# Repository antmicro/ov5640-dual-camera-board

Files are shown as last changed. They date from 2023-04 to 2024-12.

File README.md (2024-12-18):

# Antmicro's OV5640 Dual Camera Board

Copyright (c) 2017-2024 [Antmicro](https://www.antmicro.com)

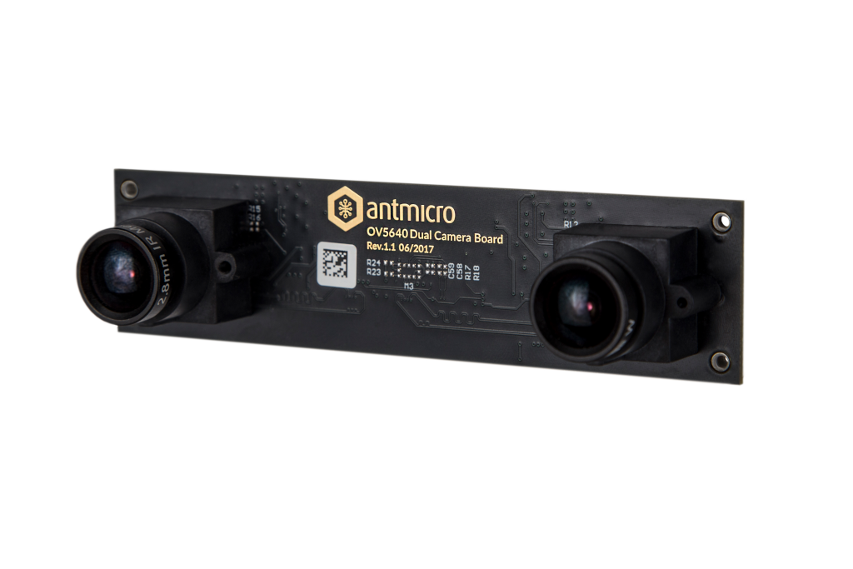
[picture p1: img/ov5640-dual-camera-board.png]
OV5640 Dual Camera Board


## Overview

This project contains open hardware design files for a camera board supporting two [OV5640](https://cdn.sparkfun.com/datasheets/Sensors/LightImaging/OV5640_datasheet.pdf) image sensors from OmniVision. 
These RGB sensors provide a rolling shutter and offer a resolution of 5MP (2591x1944).
The design files for this project are provided and maintained in KiCad.

### Project structure

The main directory contains the KiCad design files, LICENSE and README.
The remaining files are stored in the following directories:

* ``img`` - contains graphics for this README
* ``doc`` - contains generated schematics and other documentation
* ``lib`` - contains KiCad component library

## Key features

* Two OV5640 image sensors placed on a PCB
* Fastening holes spaced by 20mm for a standard S-mount lens holder
* Each sensor is accessible through an independent 2-lane MIPI CSI-2 interface
* Separate I2C buses for sensor configuration 
* Unified, 50-pin FFC interface
* On-board clock generator for driving the image sensors 

The OV5640 Dual Camera board is electrically compatible with a variety of processing platforms created by Antmicro.
Below is a list of a few selected ones:

* [Jetson Nano Baseboard](https://github.com/antmicro/jetson-nano-baseboard) supporting NVIDIA [Jetson Nano](https://developer.nvidia.com/embedded/jetson-nano), Jetson [TX2 NX](https://developer.nvidia.com/embedded/jetson-tx2-nx), Jetson [Xavier NX](https://www.nvidia.com/en-us/autonomous-machines/embedded-systems/jetson-xavier-nx/) System on Modules
* [Jetson Orin Baseboard](https://github.com/antmicro/jetson-orin-baseboard) supporting NVIDIA Jetson Orin NX, Jetson Orin Nano
* [Kria K26 Devboard](https://github.com/antmicro/kria-k26-devboard) supporting AMD-Xilinx [KRIA K26](https://www.xilinx.com/products/som/kria/k26c-commercial.html) System on Module
* [Google Coral Baseboard](https://github.com/antmicro/google-coral-baseboard) supporting [Google Coral](https://coral.ai/products/som) System on Module
* [Snapdragon 845 Baseboard](https://github.com/antmicro/snapdragon-845-baseboard) based on Quectel SA800 SoM with Qualcomm [Snapdragon 845 Mobile Platform](https://www.qualcomm.com/products/mobile/snapdragon/smartphones/snapdragon-8-series-mobile-platforms/snapdragon-845-mobile-platform)
* [Snapdragon 625 Baseboard](https://github.com/antmicro/snapdragon-625-baseboard) based on Quectel SC606T SoM with Qualcomm [Snapdragon 625 Mobile Platform](https://www.qualcomm.com/products/mobile/snapdragon/smartphones/snapdragon-6-series-mobile-platforms/snapdragon-625-mobile-platform)

## License

This project is licensed under the [Apache-2.0](LICENSE) license.

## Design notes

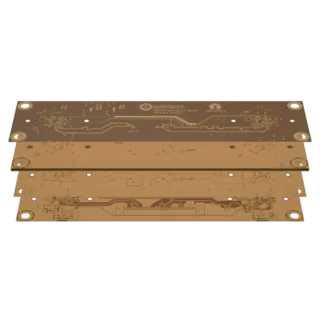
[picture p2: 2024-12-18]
assets/previews/layer1_thumbnail.webp

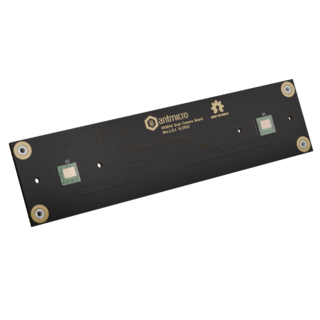
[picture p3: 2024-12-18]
assets/previews/leftT_thumbnail.png

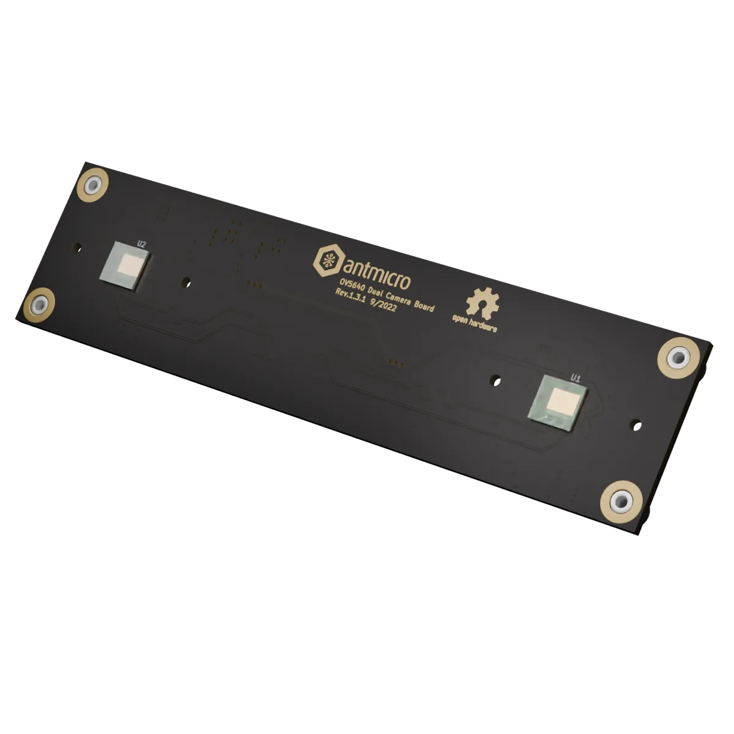
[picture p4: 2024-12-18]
assets/previews/rightT.webp

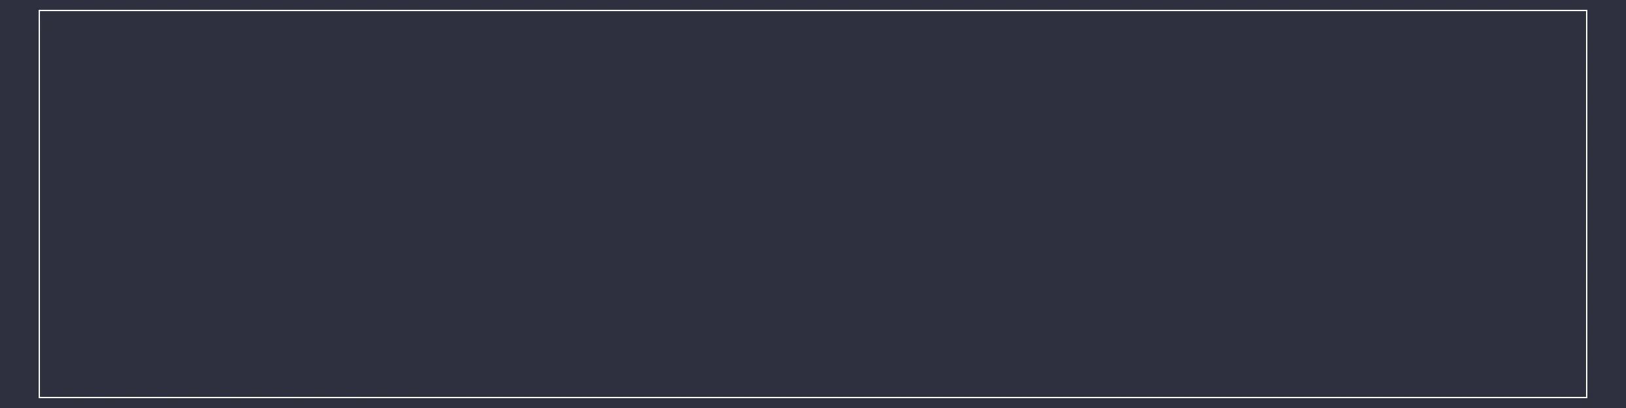
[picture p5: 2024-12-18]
assets/wireframe/wireframe_descriptions_top.webp

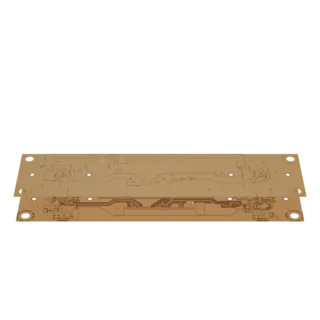
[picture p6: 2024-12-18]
assets/previews/layer3_thumbnail.webp

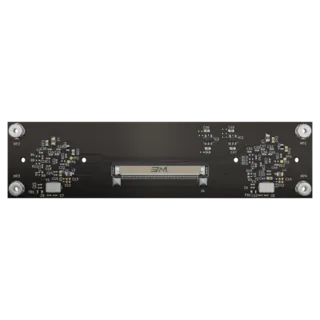
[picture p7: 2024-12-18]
assets/previews/orthoB_thumbnail.webp

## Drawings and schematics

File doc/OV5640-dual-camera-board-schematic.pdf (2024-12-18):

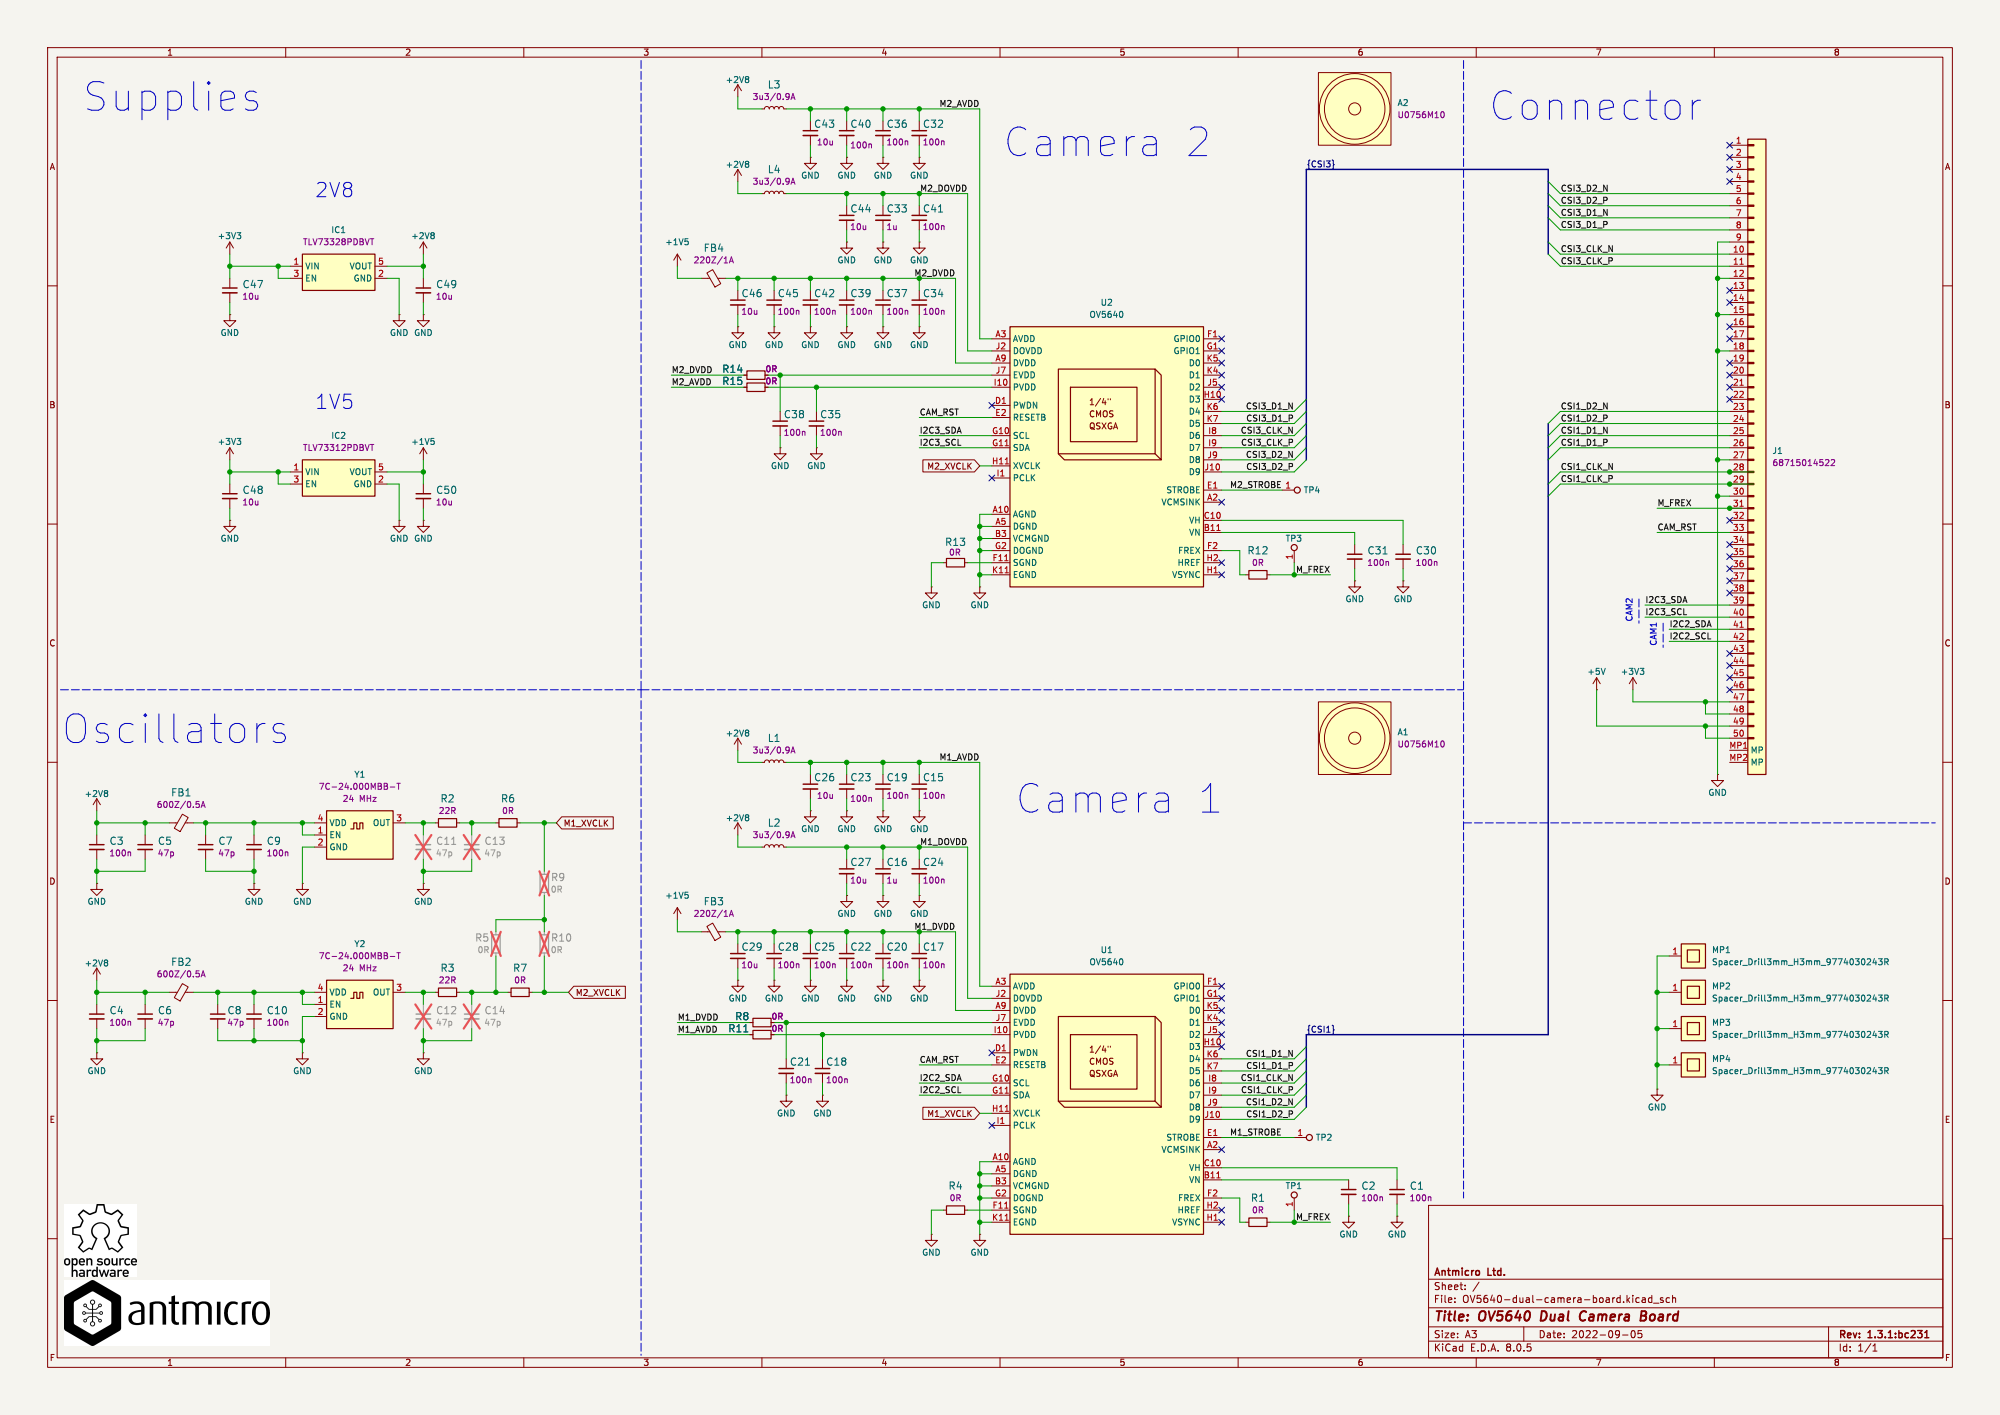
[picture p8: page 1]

Id: 1/1 Title: OV5640 Dual Camera Board

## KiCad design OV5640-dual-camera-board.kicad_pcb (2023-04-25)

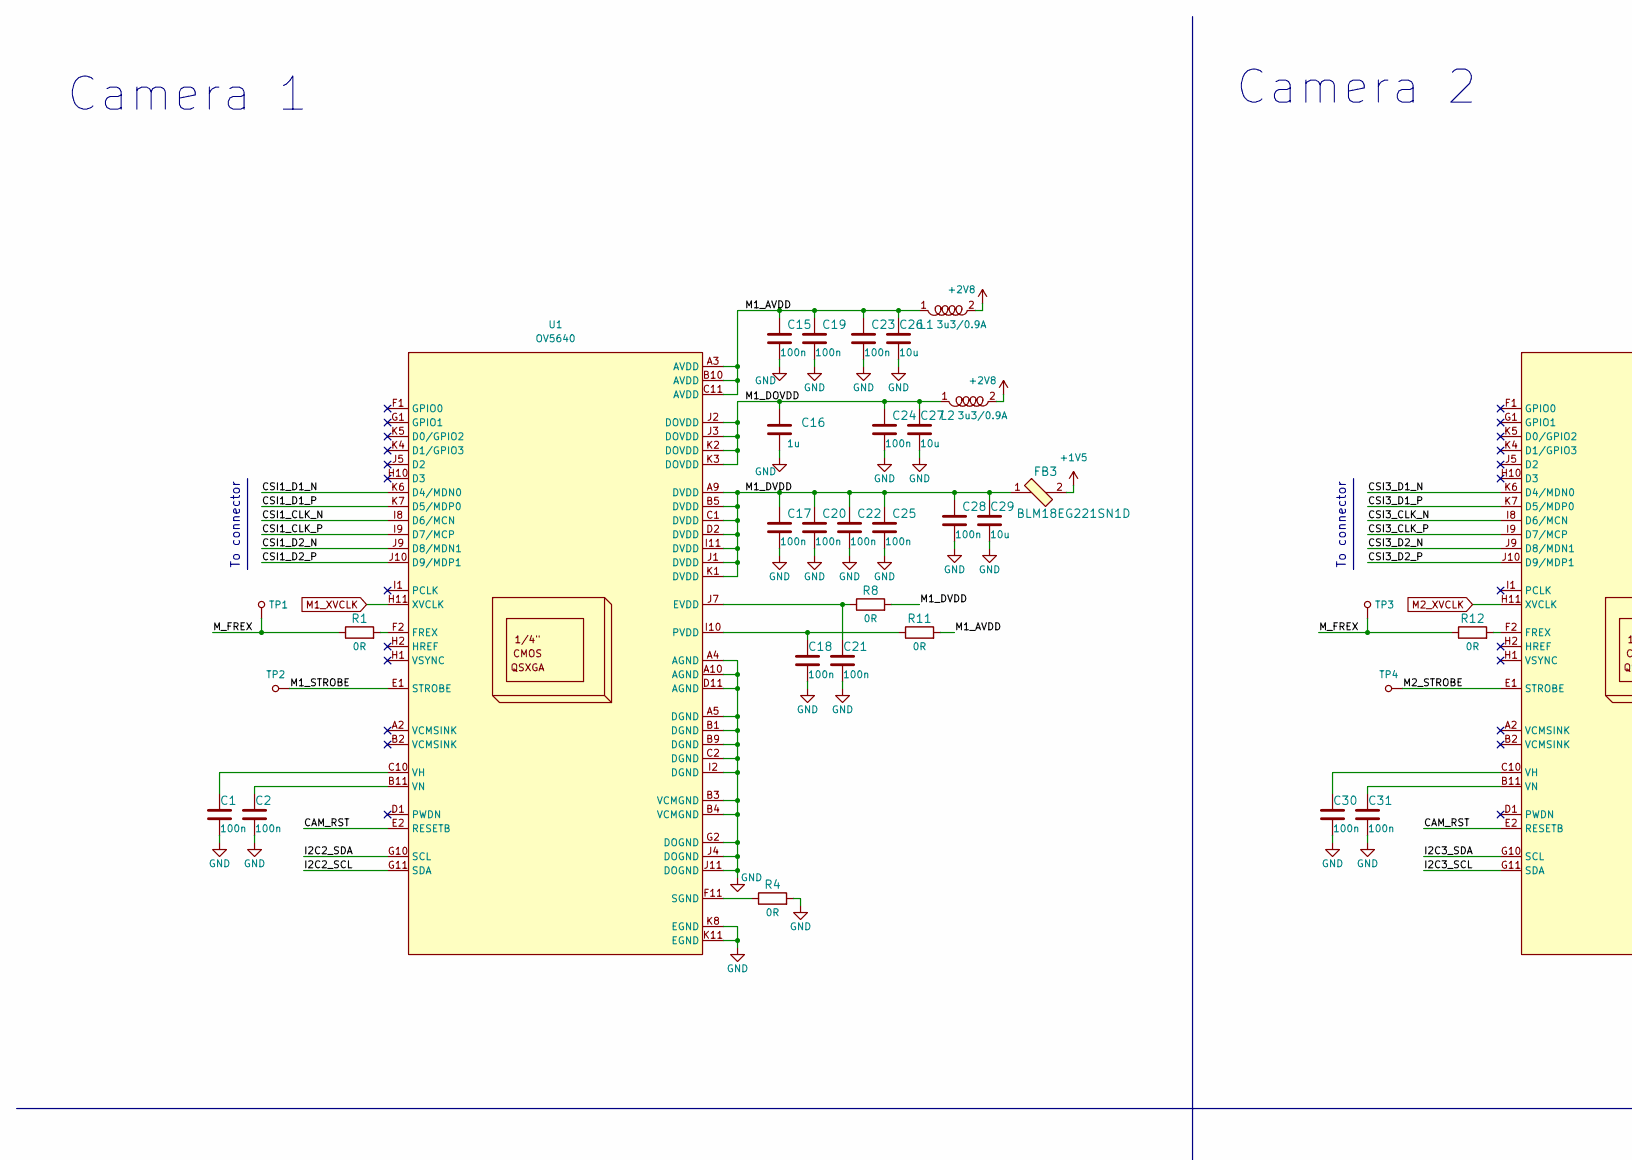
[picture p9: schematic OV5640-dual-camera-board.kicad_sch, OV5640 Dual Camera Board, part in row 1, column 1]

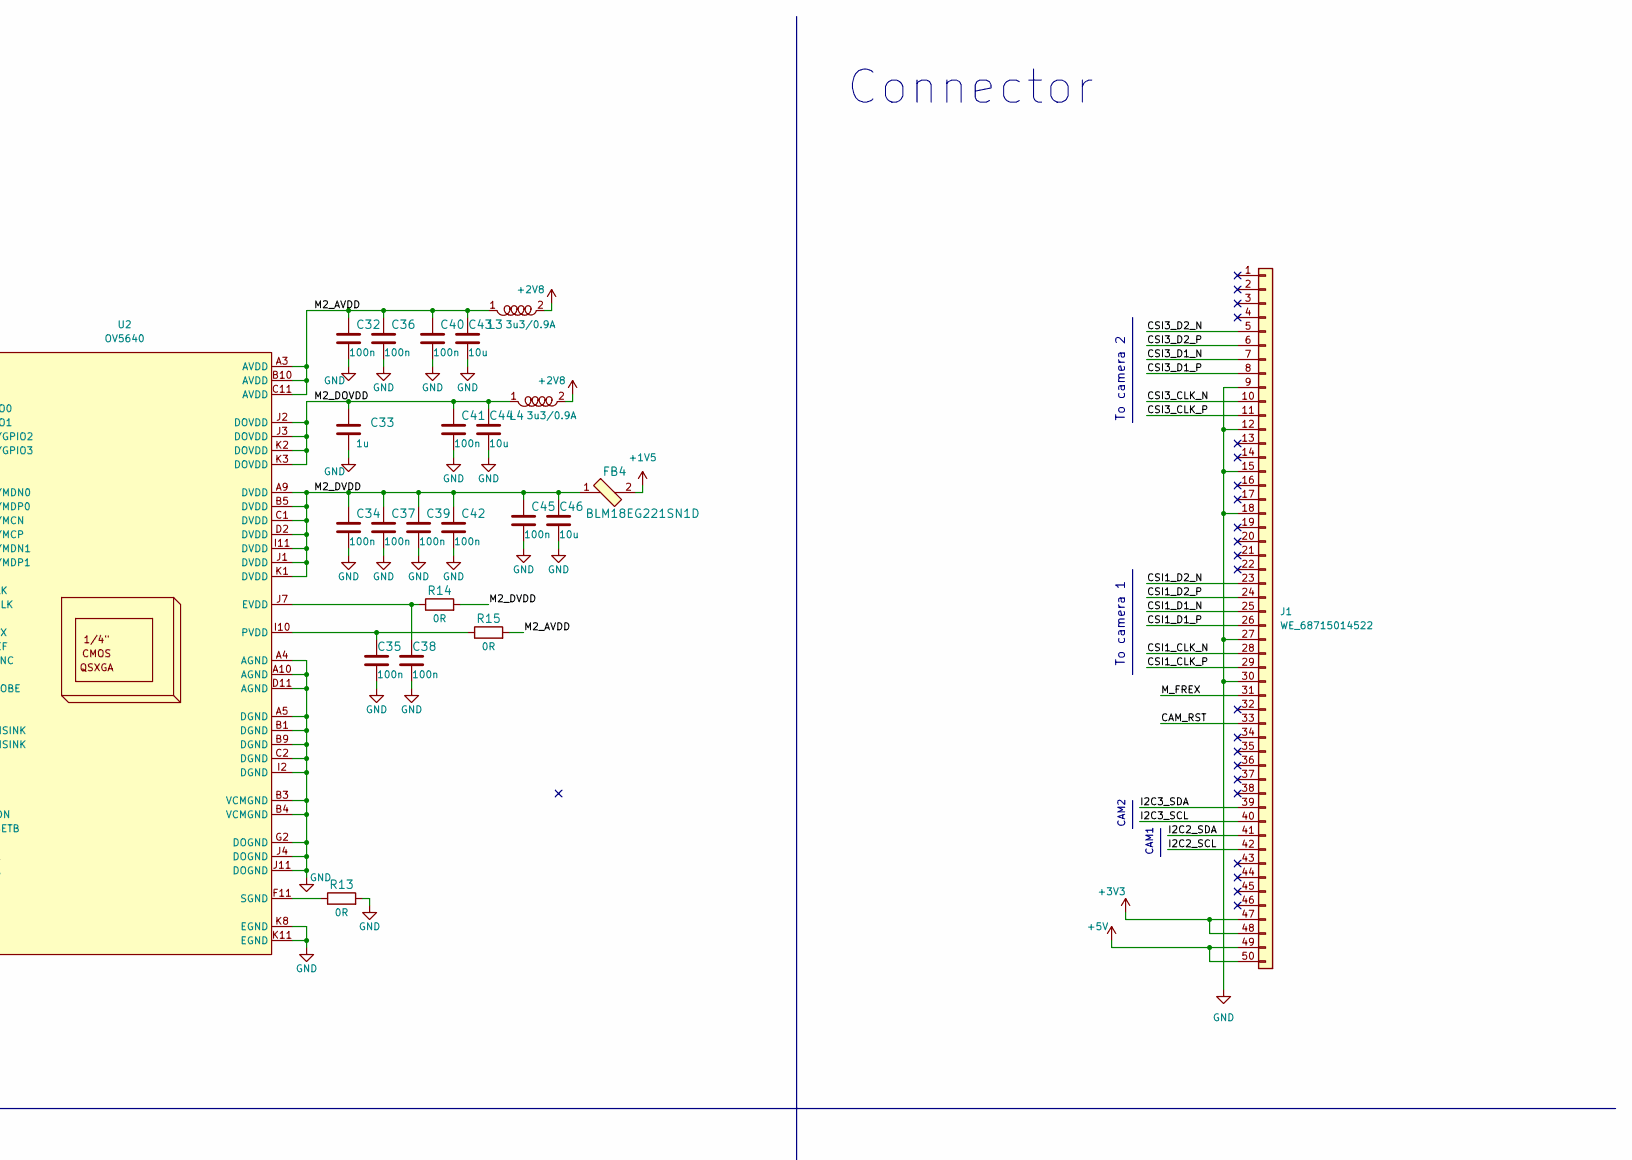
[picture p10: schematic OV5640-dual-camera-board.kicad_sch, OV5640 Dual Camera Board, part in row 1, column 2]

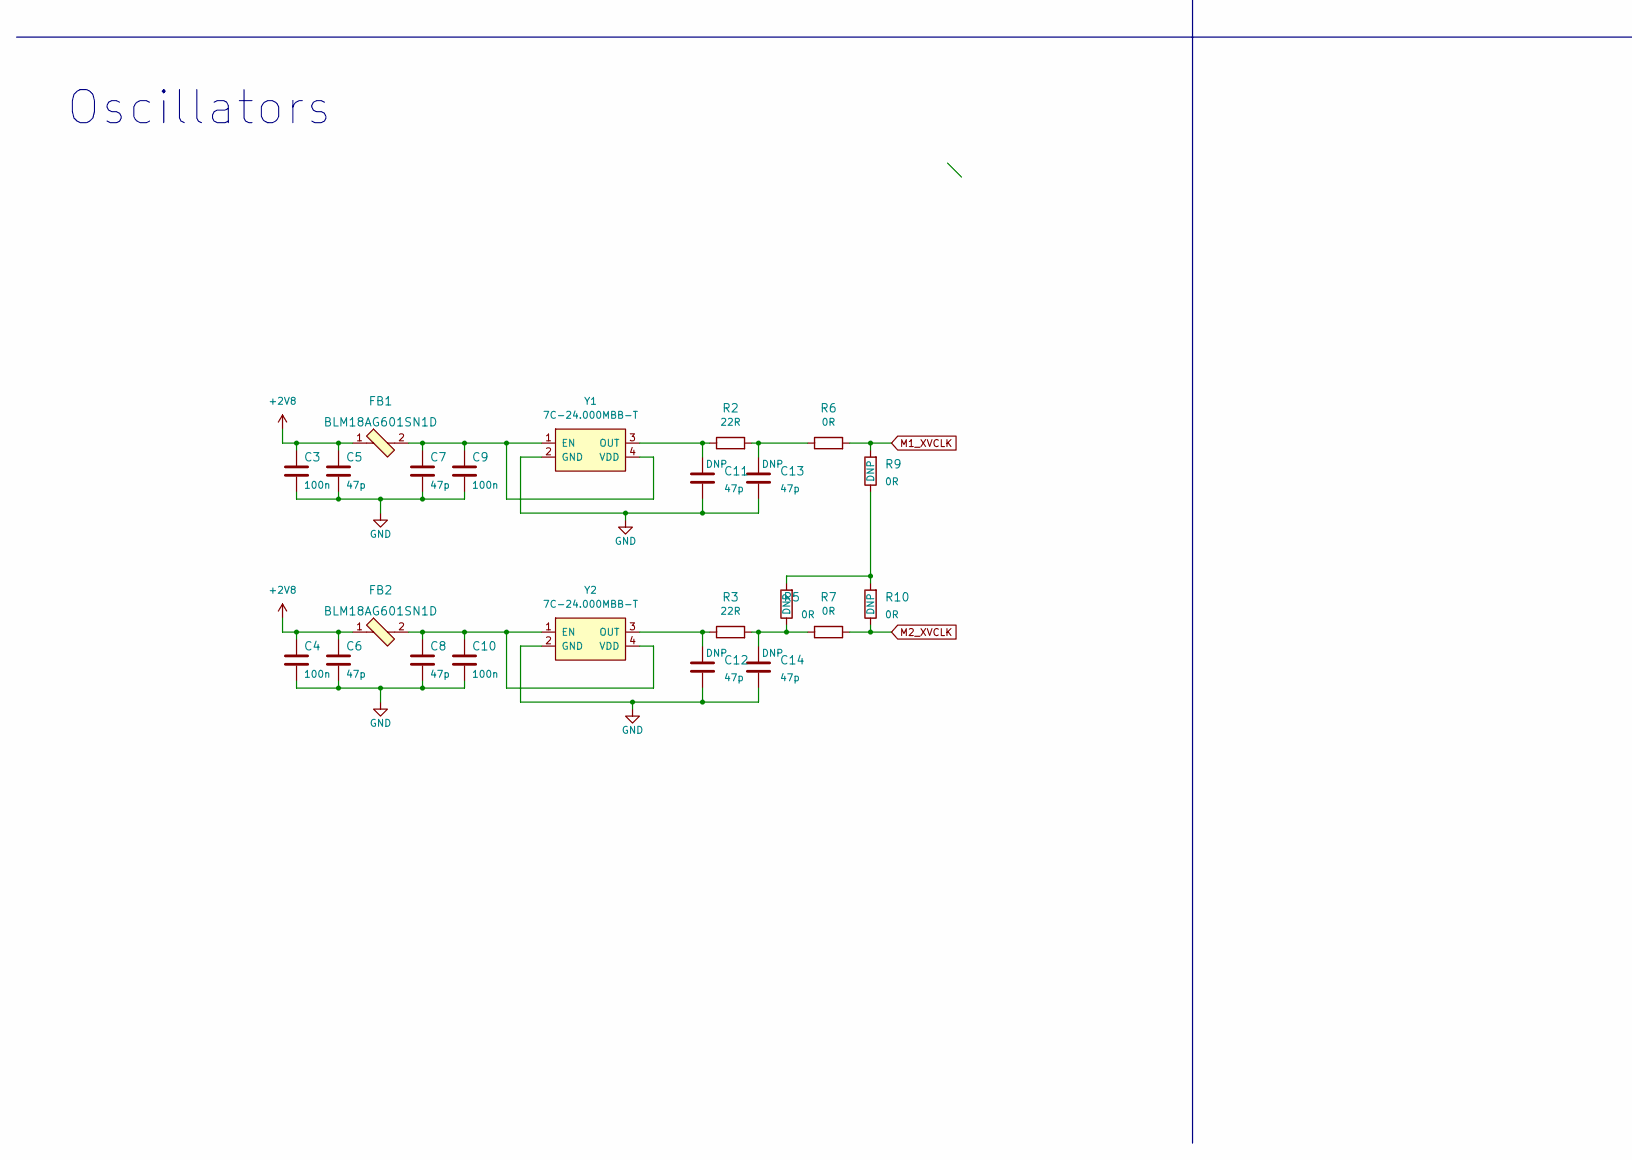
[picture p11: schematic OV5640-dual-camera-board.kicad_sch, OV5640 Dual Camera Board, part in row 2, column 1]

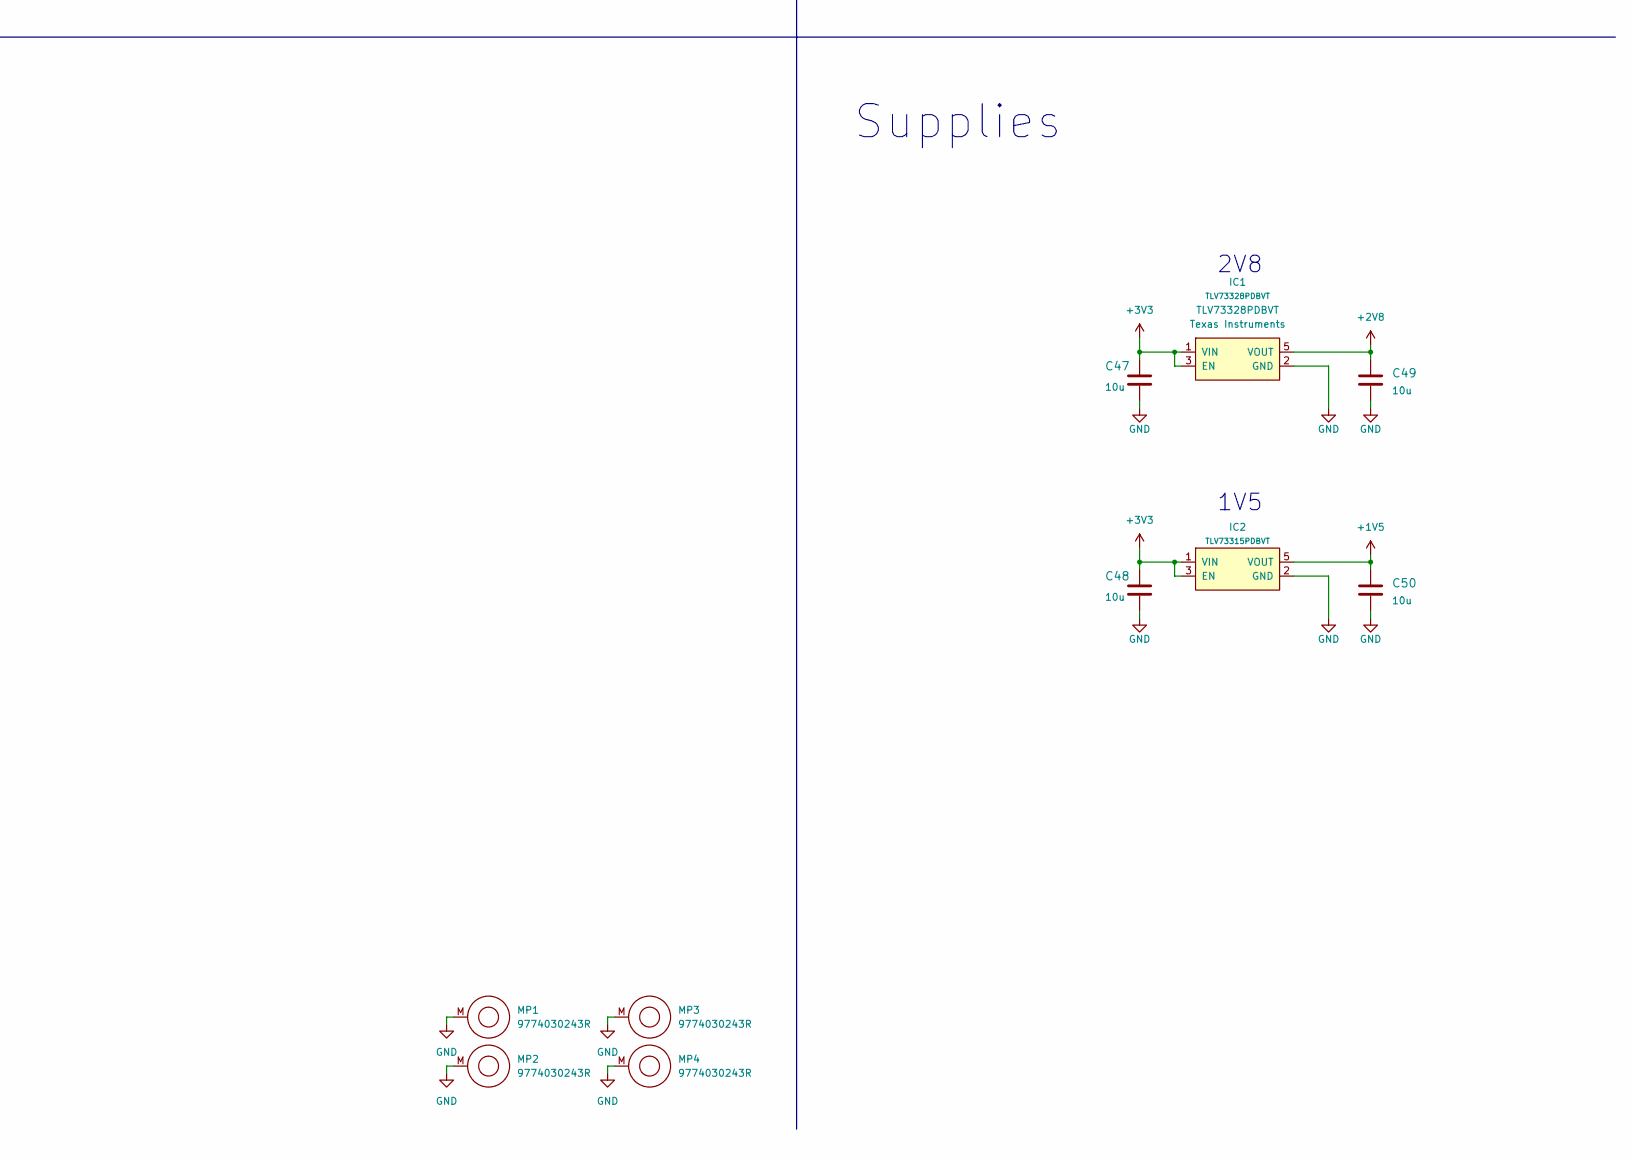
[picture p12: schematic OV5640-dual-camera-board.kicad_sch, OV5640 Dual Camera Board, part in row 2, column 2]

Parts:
C1, C2, C3, C4, C9, C10, C15, C17, C18, C19, C20, C21, C22, C23, C24, C25, C28, C30, C31, C32, C34, C35, C36, C37, C38, C39, C40, C41, C42, C45: C_100n_0402; 0402-cap; MPN GRM155R61H104KE14D
C5, C6, C7, C8, C11, C12, C13, C14: C_47p_0402; 0402-cap; MPN C0402C470J5GACTU
C16, C33: C_1u_0402; 0402-cap; MPN C1005X6S1A105K050BC
C26, C27, C29, C43, C44, C46, C47, C48, C49, C50: C_10u_0603; 0603-cap; MPN GRM188R61A106KE69D
FB1, FB2: BLM18AG601SN1D; 0603; MPN BLM18AG601SN1D
FB3, FB4: BLM18EG221SN1D; 0603; MPN BLM18EG221SN1D
IC1: TLV73328PDBVT; SOT-23-5; MPN TLV73328PDBVT
IC2: TLV73315PDBVT; SOT-23-5; MPN TLV73312PDBVT
J1: WE_68715014522; MPN 68715014522
L1, L2, L3, L4: MLP2012S3R3MT; 0805-res; MPN MLP2012S3R3MT
MP1, MP2, MP3, MP4: 9774030243R; MPN 9774030243R
R1, R4, R5, R6, R7, R8, R9, R10, R11, R12, R13, R14, R15: R_0R_0402; 0402-res; MPN ERJ2GE0R00X
R2, R3: R_22R_0402; 0402-res; MPN CRCW040222R0FKED
TP1, TP2, TP3, TP4: TP_SMD1MM; Testpoint_smd_1mm
U1, U2: OV5640; MPN OV5640
Y1, Y2: 7C-24.000MBB-T; MPN 7C-24.000MBB-T

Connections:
+1V5: C50.1, FB3.2, FB4.2, IC2.5 (VOUT)
+2V8: C3.1, C4.1, C5.1, C6.1, C49.1, FB1.1, FB2.1, IC1.5 (VOUT), L1.2, L2.2, L3.2, L4.2
+3V3: C47.1, C48.1, IC1.1 (VIN), IC1.3 (EN), IC2.1 (VIN), IC2.3 (EN), J1.47, J1.48
+5V: J1.49, J1.50
/CAM_RST: J1.33, U1.E2 (RESETB), U2.E2 (RESETB)
/CSI1_CLK_N: J1.28, U1.I8 (D6/MCN)
/CSI1_CLK_P: J1.29, U1.I9 (D7/MCP)
/CSI1_D1_N: J1.25, U1.K6 (D4/MDN0)
/CSI1_D1_P: J1.26, U1.K7 (D5/MDP0)
/CSI1_D2_N: J1.23, U1.J9 (D8/MDN1)
/CSI1_D2_P: J1.24, U1.J10 (D9/MDP1)
/CSI3_CLK_N: J1.10, U2.I8 (D6/MCN)
/CSI3_CLK_P: J1.11, U2.I9 (D7/MCP)
/CSI3_D1_N: J1.7, U2.K6 (D4/MDN0)
/CSI3_D1_P: J1.8, U2.K7 (D5/MDP0)
/CSI3_D2_N: J1.5, U2.J9 (D8/MDN1)
/CSI3_D2_P: J1.6, U2.J10 (D9/MDP1)
/I2C2_SCL: J1.42, U1.G11 (SDA)
/I2C2_SDA: J1.41, U1.G10 (SCL)
/I2C3_SCL: J1.40, U2.G11 (SDA)
/I2C3_SDA: J1.39, U2.G10 (SCL)
/M1_AVDD: C15.1, C19.1, C23.1, C26.1, L1.1, R11.2, U1.A3 (AVDD), U1.B10 (AVDD), U1.C11 (AVDD)
/M1_DOVDD: C16.1, C24.1, C27.1, L2.1, U1.J2 (DOVDD), U1.J3 (DOVDD), U1.K2 (DOVDD), U1.K3 (DOVDD)
/M1_DVDD: C17.1, C20.1, C22.1, C25.1, C28.1, C29.1, FB3.1, R8.2, U1.A9 (DVDD), U1.B5 (DVDD), U1.C1 (DVDD), U1.D2 (DVDD), U1.I11 (DVDD), U1.J1 (DVDD), U1.K1 (DVDD)
/M1_STROBE: TP2.1, U1.E1 (STROBE)
/M2_AVDD: C32.1, C36.1, C40.1, C43.1, L3.1, R15.2, U2.A3 (AVDD), U2.B10 (AVDD), U2.C11 (AVDD)
/M2_DOVDD: C33.1, C41.1, C44.1, L4.1, U2.J2 (DOVDD), U2.J3 (DOVDD), U2.K2 (DOVDD), U2.K3 (DOVDD)
/M2_DVDD: C34.1, C37.1, C39.1, C42.1, C45.1, C46.1, FB4.1, R14.2, U2.A9 (DVDD), U2.B5 (DVDD), U2.C1 (DVDD), U2.D2 (DVDD), U2.I11 (DVDD), U2.J1 (DVDD), U2.K1 (DVDD)
/M2_STROBE: TP4.1, U2.E1 (STROBE)
/M_FREX: J1.31, R1.1, R12.1, TP1.1, TP3.1
GND: C1.2, C2.2, C3.2, C4.2, C5.2, C6.2, C7.2, C8.2, C9.2, C10.2, C11.2, C12.2, C13.2, C14.2, C15.2, C16.2, C17.2, C18.2, C19.2, C20.2, C21.2, C22.2, C23.2, C24.2, C25.2, C26.2, C27.2, C28.2, C29.2, C30.2, C31.2, C32.2, C33.2, C34.2, C35.2, C36.2, C37.2, C38.2, C39.2, C40.2, C41.2, C42.2, C43.2, C44.2, C45.2, C46.2, C47.2, C48.2, C49.2, C50.2, IC1.2 (GND), IC2.2 (GND), J1.9, J1.12, J1.15, J1.18, J1.27, J1.30, MP1.M, MP2.M, MP3.M, MP4.M, R4.2, R13.2, U1.A4 (AGND), U1.A5 (DGND), U1.A10 (AGND), U1.B1 (DGND), U1.B3 (VCMGND), U1.B4 (VCMGND), U1.B9 (DGND), U1.C2 (DGND), U1.D11 (AGND), U1.G2 (DOGND), U1.I2 (DGND), U1.J4 (DOGND), U1.J11 (DOGND), U1.K8 (EGND), U1.K11 (EGND), U2.A4 (AGND), U2.A5 (DGND), U2.A10 (AGND), U2.B1 (DGND), U2.B3 (VCMGND), U2.B4 (VCMGND), U2.B9 (DGND), U2.C2 (DGND), U2.D11 (AGND), U2.G2 (DOGND), U2.I2 (DGND), U2.J4 (DOGND), U2.J11 (DOGND), U2.K8 (EGND), U2.K11 (EGND), Y1.2 (GND), Y2.2 (GND)
M1_XVCLK: R6.2, R9.2, U1.H11 (XVCLK)
M2_XVCLK: R7.1, R10.1, U2.H11 (XVCLK)
unnamed: C1.1, U1.C10 (VH)
unnamed: C2.1, U1.B11 (VN)
unnamed: C7.1, C9.1, FB1.2, Y1.1 (EN), Y1.4 (VDD)
unnamed: C8.1, C10.1, FB2.2, Y2.1 (EN), Y2.4 (VDD)
unnamed: C11.1, R2.1, Y1.3 (OUT)
unnamed: C12.1, R3.1, Y2.3 (OUT)
unnamed: C13.1, R2.2, R6.1
unnamed: C14.1, R3.2, R5.1, R7.2
unnamed: C18.1, R11.1, U1.I10 (PVDD)
unnamed: C21.1, R8.1, U1.J7 (EVDD)
unnamed: C30.1, U2.C10 (VH)
unnamed: C31.1, U2.B11 (VN)
unnamed: C35.1, R15.1, U2.I10 (PVDD)
unnamed: C38.1, R14.1, U2.J7 (EVDD)
unnamed: R1.2, U1.F2 (FREX)
unnamed: R4.1, U1.F11 (SGND)
unnamed: R5.2, R9.1, R10.2
unnamed: R12.2, U2.F2 (FREX)
unnamed: R13.1, U2.F11 (SGND)

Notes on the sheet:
Camera 1
To connector
Supplies
To camera 1
Connector
1V5
CAM1
Oscillators
2V8
CAM2
Camera 2
To camera 2

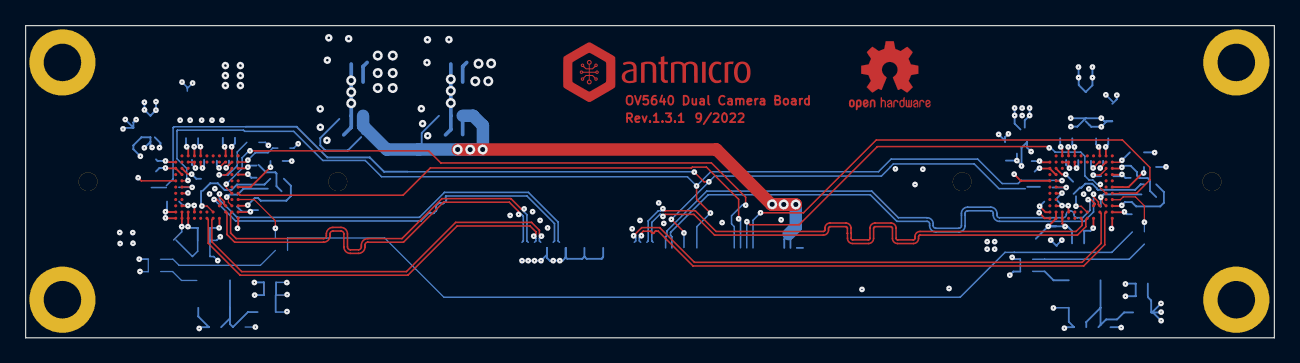
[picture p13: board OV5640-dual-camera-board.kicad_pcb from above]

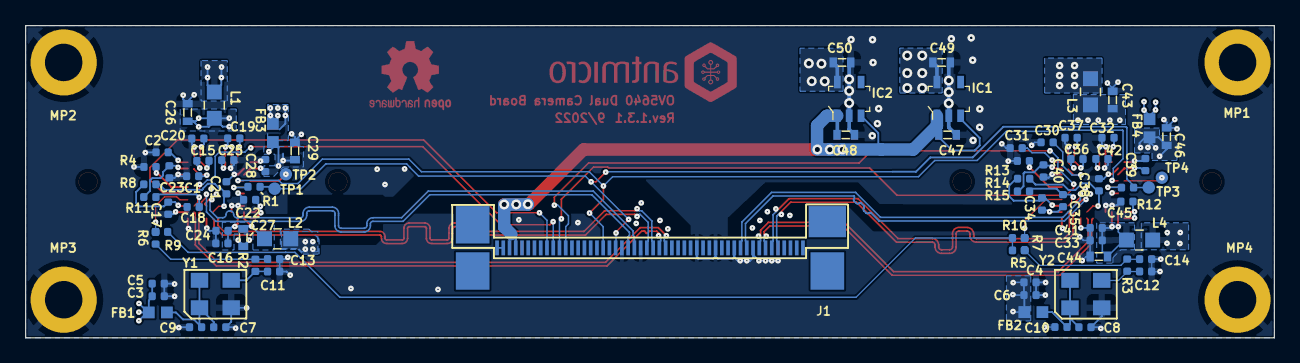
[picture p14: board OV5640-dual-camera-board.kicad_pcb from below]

Board: 4 copper layers, 100.0 x 25.0 mm, 88 parts (86 on the bottom side), 52 nets.

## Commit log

2023-04-25 Add initial KiCad desgin files
    [OV5640-dual-camera-board.kicad_pcb, OV5640-dual-camera-board.kicad_sch]
2024-12-18 Add OHP assets
    [stackup.csv]

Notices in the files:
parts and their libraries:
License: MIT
